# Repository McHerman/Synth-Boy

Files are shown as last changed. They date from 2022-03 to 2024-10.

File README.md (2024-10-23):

# Synth-Boy
## Probably the worlds smallest analog USB powered parafonic synthesizer. 

SB_V1 19 v1

## Techical details 

The Synthboy is an analog 3 oscilator FM-enabled parafonic synthesizer, with a 4 pole voltage controlled filter, an analog ADSR envelope generator and onboard beyboard and TRS Midi control. 
The whole thing is powered from a single protected USB-C input. 

SB V1 21024_1

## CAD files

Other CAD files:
Cad models/Cad models.f3d

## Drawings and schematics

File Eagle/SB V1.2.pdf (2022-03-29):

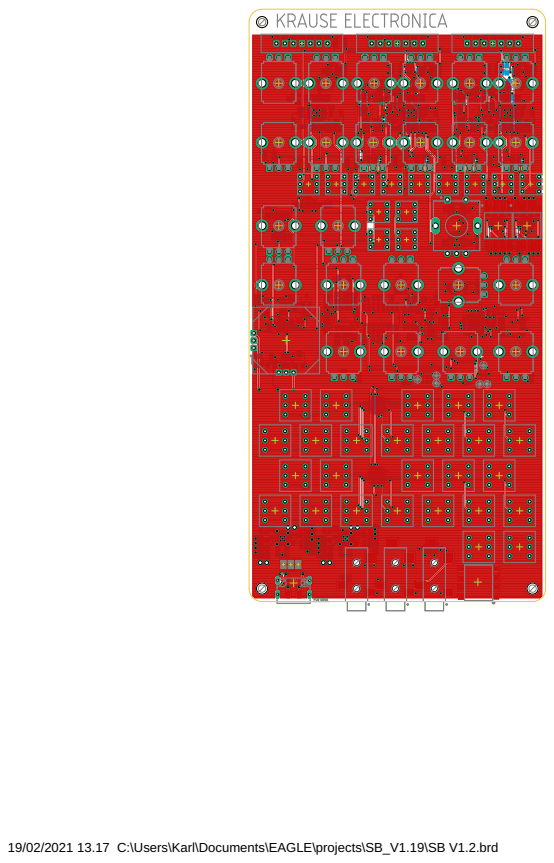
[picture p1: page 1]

19/02/2021 13.17 C:\Users\Karl\Documents\EAGLE\projects\SB_V1.19\SB V1.2.brd

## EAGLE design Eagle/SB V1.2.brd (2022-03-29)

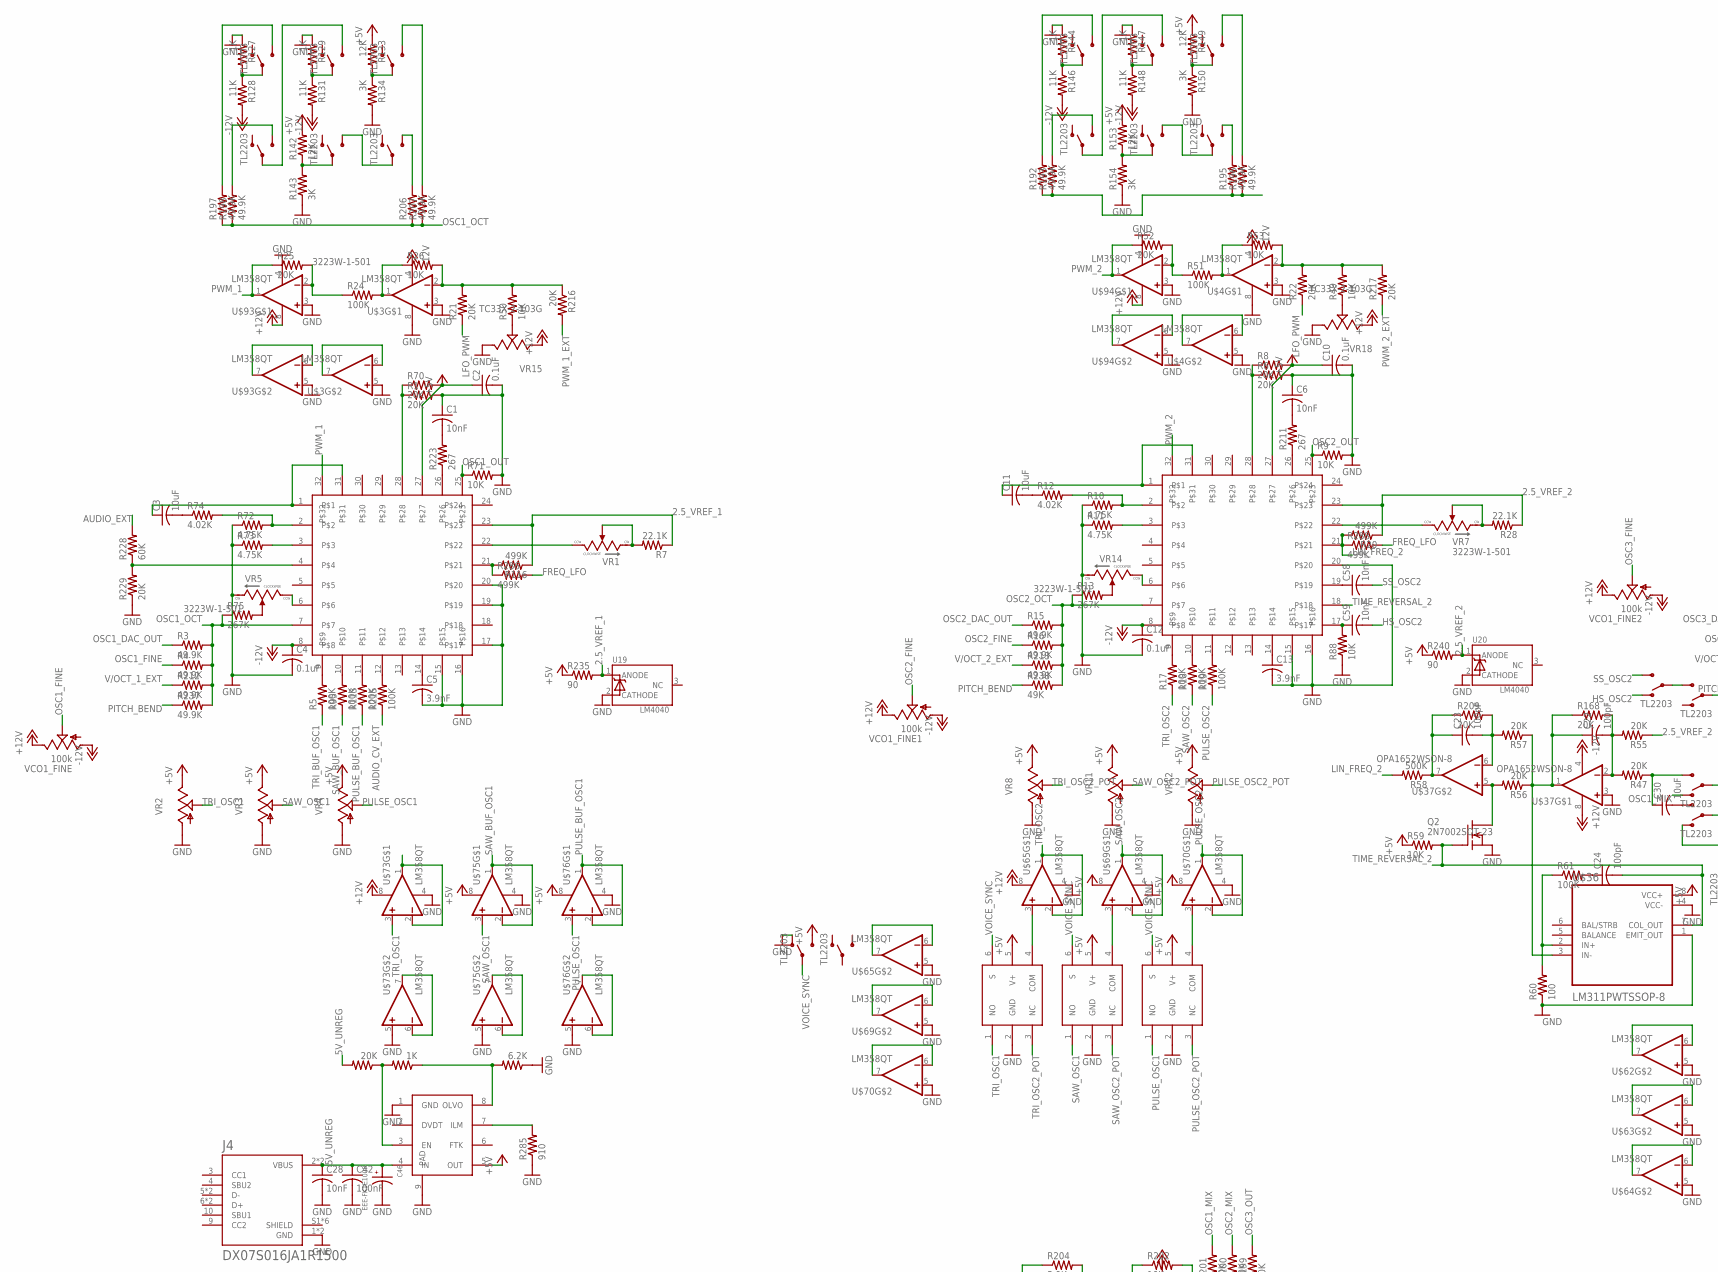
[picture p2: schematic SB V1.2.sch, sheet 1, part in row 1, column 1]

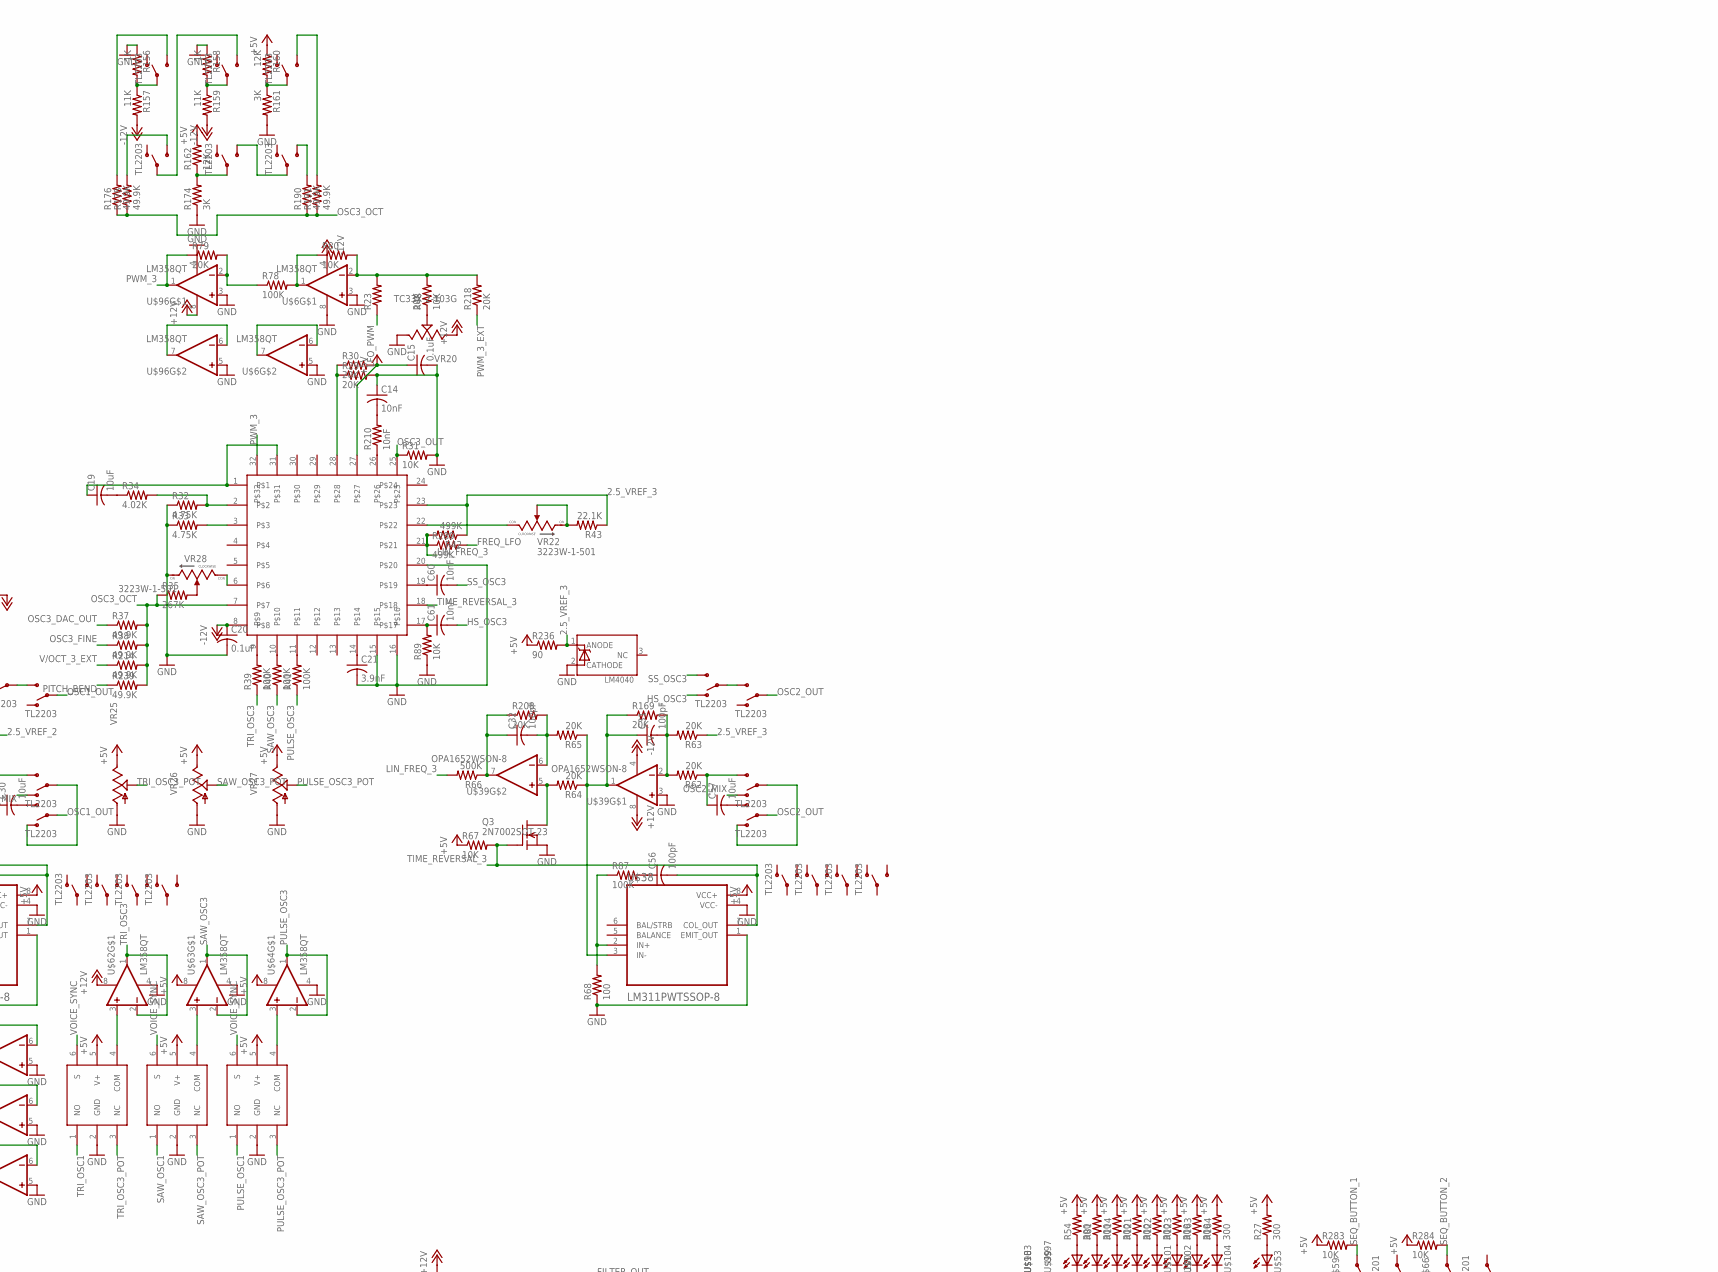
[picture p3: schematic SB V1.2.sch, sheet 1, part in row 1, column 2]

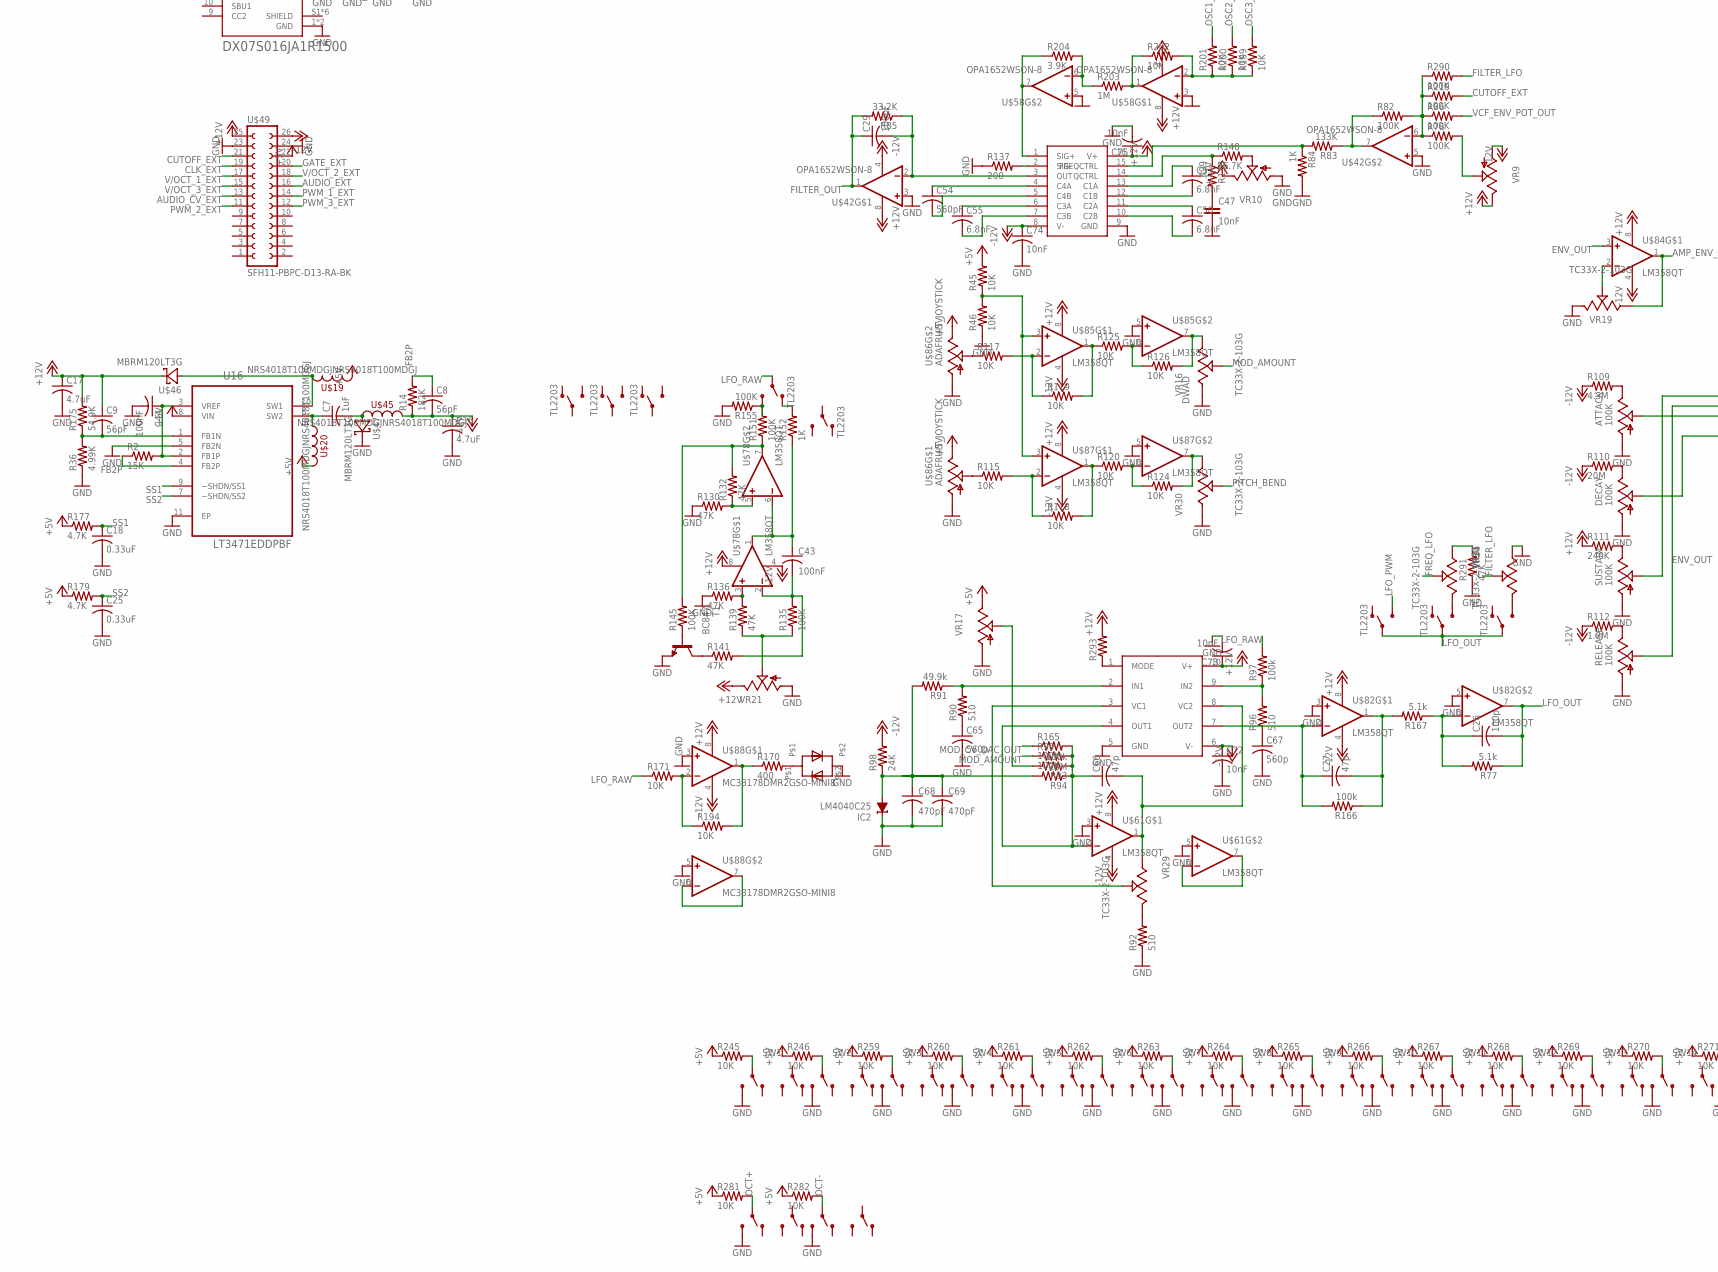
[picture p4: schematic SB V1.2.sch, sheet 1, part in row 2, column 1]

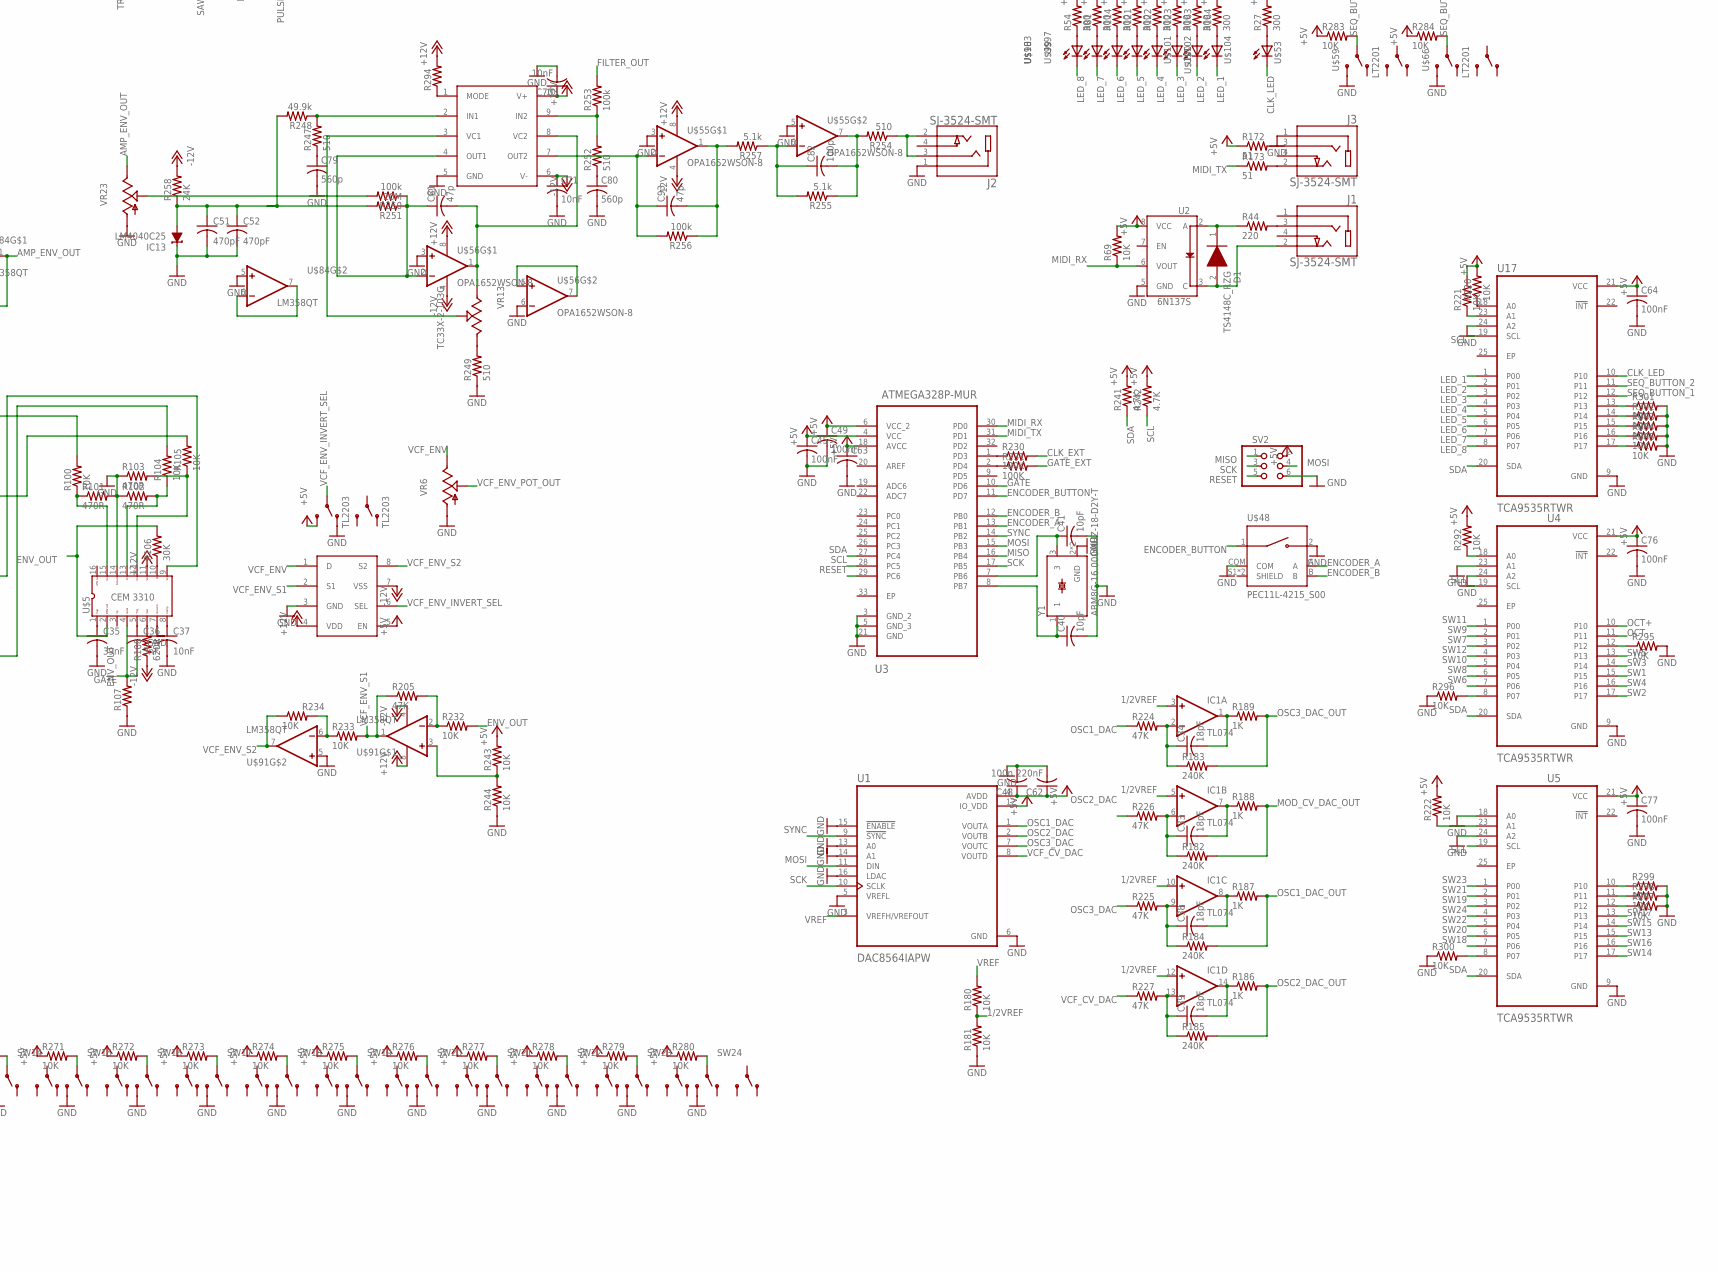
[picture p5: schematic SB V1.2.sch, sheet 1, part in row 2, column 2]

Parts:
1.2K: 1K; R0402
1_DOWN, 1_UP, 2_DOWN, 2_UP, 3_DOWN, 3_UP: TL2203
4.3K: 20K; R0402
ATTACK: 100K; 9MM_SNAP-IN_POT
C1, C6, C14, C37, C47, C58, C59, C60, C61, C70, C71, C72, C73, C74, C75: 10nF; C0402
C2, C4, C10, C12, C15, C20: 0.1uF; C0402
C3, C11, C19, C30, C57: 10uF; C0603
C5, C13, C21: 3.9nF; C0603
C7: 1uF; C0805
C8, C9: 56pF; C0402
C16, C17: 4.7uF; C1206
C18, C25: 0.33uF; C0402
C22, C23, C24, C29, C31, C32, C56: 100pF; C0402
C26, C82: 100p; C0402
C27, C66, C81, C93: 47p; C0402
C28: 10nF; C0603
C33, C34, C38, C39: 18pF; C0402
C35: 39nF; C0402
C36: 3nF; C0402
C40, C41: 10pF; C0402
C42: 100nF; C0603
C43, C44, C45, C49, C64, C76, C77: 100nF; C0402
C46: EEE-FK1E100R; CAPAE430X610N
C48: 100n; C0402
C50, C53, C55: 6.8nF; C0805
C51, C52, C68, C69: 470pF; C0402
C54: 560pF; C0805
C62: 220nF; C0402
C63: C-USC0402; C0402
C65, C67, C79, C80: 560p; C0402
D1: TS4148C_RZG; DIOC1608X75N
DECAY: 100K; 9MM_SNAP-IN_POT
IC1: TL074; TSSOP14
IC2, IC13: LM4040C25; DBZ_R-PDSO-G3
J1, J2, J3: SJ-3524-SMT; CUI_SJ-3524-SMT
J4: DX07S016JA1R1500; JAE_DX07S016JA1R1500
Q2, Q3: 2N7002SOT-23; SOT23-BEC
R1, R6, R8, R21, R22, R23, R25, R29, R30, R47, R52, R55, R56, R57, R62, R63, R64, R65, R70, R79, R168, R169, R208, R209, R216, R217, R218, R229: 20K; R0402
R2: 15K; R0402
R3, R4, R15, R16, R37, R38, R176, R178, R190, R191, R192, R193, R195, R196, R197, R198, R206, R207, R212, R213, R214, R237, R239: 49.9K; R0402
R5, R17, R18, R19, R24, R39, R40, R41, R51, R61, R76, R78, R82, R86, R87, R95, R99, R113, R135, R145, R151, R155, R165, R215, R219, R230, R231, R290: 100K; R0402
R7, R28, R43: 22.1K; R0402
R9, R26, R31, R45, R46, R48, R49, R50, R53, R59, R67, R69, R71, R80, R88, R89, R100, R104, R105, R107, R115, R117, R118, R119, R120, R124, R125, R126, R171, R180, R181, R194, R199, R200, R201, R202, R220, R221, R222, R232, R233, R234, R243, R244, R245, R246, R259, R260, R261, R262, R263, R264, R265, R266, R267, R268, R269, R270, R271, R272, R273, R274, R275, R276, R277, R278, R279, R280, R281, R282, R283, R284, R292, R295, R296, R297, R298, R299, R300, R301, R302, R303, R304, R305: 10K; R0402
R10, R11, R32, R33, R72, R73: 4.75K; R0402
R12, R34, R74: 4.02K; R0402
R13, R35, R75: 267K; R0402
R14: 182K; R0402
R20, R42, R116, R286, R288, R289: 499K; R0402
R27, R54, R81, R114, R121, R122, R123, R163, R164: 300; R0603
R36: 4.99K; R0402
R44: 220; R0402
R58, R66: 500K; R0402
R60, R68: 100; R0402
R77, R167, R255, R257: 5.1k; R0402
R83: 133K; R0402
R84, R127, R129, R144, R147, R152, R156, R158, R186, R187, R188, R189: 1K; R0402
R85: 33.2K; R0402
R90, R92, R96, R247, R249, R252, R254: 510; R0402
R91, R248: 49.9k; R0402
R93, R97, R166, R250, R253, R256: 100k; R0402
R94, R110, R251: 20M; R0402
R98, R258: 24K; R0402
R101, R102, R103: 470R; R0402
R106: 30K; R0402
R108: 620R; R0402
R109: 4.3M; R0402
R111, R182, R183, R184, R185: 240K; R0402
R112: 1.8M; R0402
R128, R131, R146, R148, R157, R159: 11K; R0402
R130, R132, R136, R139, R141, R205, R224, R225, R226, R227, R291: 47K; R0402
R133, R142, R149, R153, R160, R162: 12K; R0402
R134, R143, R150, R154, R161, R174: 3K; R0402
R137: 200; R0402
R138: 499; R0402
R140: 26.7K; R0402
R170: 400; R0603
R172, R173: 51; R0402
R175: 54.9K; R0402
R177, R179, R241, R242: 4.7K; R0402
R203: 1M; R0402
R204: 3.9K; R0402
R210: 10nF; R0402
R211, R223: 267; R0402
R228: 60K; R0402
R235, R236, R240: 90; R0402
R238: 49K; R0402
R285: 910; R0402
R287: 6.2K; R0402
R293, R294: R-US_R0402; R0402
RELEASE: 100K; 9MM_SNAP-IN_POT
SUSTAIN: 100K; 9MM_SNAP-IN_POT
SV2: PINHD-2X3; 2X03
T1: BC847; SOT23
U1: DAC8564IAPW; SOP65P640X120-16N
U2: 6N137S; 8-SMD
U3: ATMEGA328P-MUR; QFN50P500X500X100-33N
U4, U5, U17: TCA9535RTWR; QFN50P400X400X80-25N
U16: LT3471EDDPBF; DFN300X300X80-11N
U19, U20, U21: LM4040; SOT23-3
U$1, U$2, U$7: SSI2130_V2QFN-32; QFN40P400X400X80-33T270N
U$3, U$4, U$6, U$61, U$62, U$63, U$64, U$65, U$69, U$70, U$73, U$75, U$76, U$78, U$82, U$84, U$85, U$87, U$91, U$93, U$94, U$96: LM358QT; SON50P200X200X60-9N
U$5: AS3310DSO-16; SO16
U$8, U$35, U$40, U$41, U$43, U$44, U$51, U$57, U$60, U$71, U$72, U$77, U$79, U$80, U$81, U$92, U$95: TL2203
U$9, U$10, U$11, U$12, U$13, U$14, U$15, U$16, U$17, U$18, U$21, U$22, U$23, U$24, U$25, U$26, U$27, U$28, U$29, U$30, U$31, U$32, U$33, U$34, U$59, U$66, U$67, U$68: LT2201
U$19, U$20, U$45: NRS4018T100MDGJNRS4018T100MDGJ; INDDFN400X400X180-2N
U$36, U$38: LM311PWTSSOP-8; TSSOP8
U$37, U$39, U$42, U$55, U$56, U$58: OPA1652WSON-8; SON50P300X300X80-9T120X200N
U$46, U$47: MBRM120LT3G; DIO_MBRM110LT1G
U$48: PEC11L-4215_S00; XDCR_PEC11R-4215F-S0024
U$49: SFH11-PBPC-D13-RA-BK; FE13-2W
U$53, U$97, U$98, U$99, U$100, U$101, U$102, U$103, U$104: WP914HDT
U$54, U$90: SSI2162SSOP10; SOP100P600X150-10N
U$74: WP483SRSGW
U$83: SSI2144; TSSOP16
U$86: ADAFRUIT_JOYSTICK; ADAFRUIT-JOYSTICK
U$88: MC33178DMR2GSO-MINI8; SOP65P490X110-8N
U$89: TMUX6219DGKRSO-MINI8; SOP65P490X110-8N
U$105, U$106, U$107, U$108, U$109, U$110: NC7SB3157P6XSC-70-6; SOT65P210X110-6N
U$111: TPS259620DDARSOIC-8; SOIC127P600X170-9T240X310N
VCO1_FINE, VCO1_FINE1, VCO1_FINE2: 100k; 9MM_SNAP-IN_POT
VR1, VR5, VR7, VR14, VR22, VR28: 3223W-1-501; TRIM_3223W-1-501
VR2, VR3, VR4, VR6, VR8, VR9, VR10, VR11, VR12, VR17, VR23, VR25, VR26, VR27: 9MM_SNAP-IN_POT_; 9MM_SNAP-IN_POT
VR13, VR15, VR16, VR18, VR19, VR20, VR24, VR29, VR30, VR31: TC33X-2-103G; TRIMMER_TC33X-2-103G
VR21: 9MM_SNAP-IN_POT_NOSNAP_; 9MM_SNAP-IN_POT
Y1: ABM8G-16.000MHZ-18-D2Y-T; OSCSC320X250X100N

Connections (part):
1/2VREF: IC1.3 (+IN), IC1.5 (+IN), IC1.10 (+IN), IC1.12 (+IN), R180.1, R181.2
2.5_VREF_1: R7.1, R116.1, R235.2, U19.1 (ANODE), U$7.23
2.5_VREF_2: R20.1, R28.1, R55.1, R240.2, U20.1 (ANODE), U$1.23
2.5_VREF_3: R42.1, R43.1, R63.1, R236.2, U21.1 (ANODE), U$2.23
5V_UNREG: 4.3K.2, C28.1, C42.1, C46.1, J4.2 (VBUS), J4.11 (VBUS), U$111.4 (IN)
+5V: C2.1, C10.1, C15.1, C45.1, C48.1, C49.1, C62.1, C63.1, C64.1, C76.1, C77.1, R8.2, R27.2, R30.2, R45.2, R54.2, R59.1, R67.1, R69.2, R70.2, R81.2, R114.2, R121.2, R122.2, R123.2, R133.1, R142.2, R149.1, R153.2, R160.1, R162.2, R163.2, R164.2, R172.1, R177.1, R179.1, R220.2, R221.2, R222.2, R235.1, R236.1, R240.1, R241.2, R242.2, R243.2, R245.1, R246.1, R259.1, R260.1, R261.1, R262.1, R263.1, R264.1, R265.1, R266.1, R267.1, R268.1, R269.1, R270.1, R271.1, R272.1, R273.1, R274.1, R275.1, R276.1, R277.1, R278.1, R279.1, R280.1, R281.1, R282.1, R283.1, R284.1, R292.2, SV2.2, U1.4 (AVDD), U1.12 (IO_VDD), U2.8 (VCC), U3.4 (VCC), U3.6 (VCC_2)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
+12V: C9.1, C17.1, C70.1, C73.1, C75.1, IC1.4 (V+), R111.1, R175.2, R293.2, R294.2, U$5.11, U$37.8 (V+), U$39.8 (V+), U$42.8 (V+), U$46.1 (K), U$49.25, U$54.10 (V+), U$55.8 (V+), U$56.8 (V+), U$58.8 (V+), U$61.8 (V+), U$62.8 (V+), U$65.8 (V+), U$73.8 (V+), U$78.8 (V+), U$82.8 (V+), U$83.16 (V+), U$84.8 (V+), U$85.8 (V+), U$87.8 (V+), U$88.8 (V+), U$89.4 (VDD), U$90.10 (V+), U$91.8 (V+), U$93.8 (V+), U$94.8 (V+), U$96.8 (V+), VCO1_FINE.3 (E), VCO1_FINE1.3 (E), VCO1_FINE2.3 (E), VR9.3 (E), VR10.3 (E), VR15.1 (CCW), VR18.1 (CCW), VR20.1 (CCW), VR21.3 (E)
-12V: C4.1, C8.2, C12.1, C16.1, C20.1, C71.1, C72.1, C74.1, IC1.11 (V-), R14.1, R98.2, R108.1, R109.1, R110.1, R112.1, R128.2, R131.2, R146.2, R148.2, R157.2, R159.2, R258.2, U$1.8, U$2.8, U$3.4 (V-), U$4.4 (V-), U$6.4 (V-), U$7.8, U$37.4 (V-), U$39.4 (V-), U$42.4 (V-), U$45.2, U$49.26, U$54.6 (V-), U$55.4 (V-), U$56.4 (V-), U$58.4 (V-), U$61.4 (V-), U$78.4 (V-), U$82.4 (V-), U$83.8 (V-), U$84.4 (V-), U$85.4 (V-), U$87.4 (V-), U$88.4 (V-), U$89.7 (VSS), U$90.6 (V-), U$91.4 (V-), VCO1_FINE.1 (A), VCO1_FINE1.1 (A), VCO1_FINE2.1 (A), VR9.1 (A)
AMP_ENV_OUT: U$84.1 (OUT), VR19.1 (CCW), VR23.3 (E)
AREF_-2.1: C51.1, C52.1, IC13.2 (A), R248.2, R251.2, R258.1
AREF_-2.2: C68.1, C69.1, IC2.2 (A), R91.2, R94.2, R98.1
AUDIO_CV_EXT: R215.1, U$49.13
AUDIO_EXT: R228.2, U$49.16
A_IN_O2B1: R247.2, R248.1, U$54.2 (IN1)
A_IN_O2B2: R90.2, R91.1, U$90.2 (IN1)
CLK_EXT: R230.2, U$49.19
CLK_LED: U17.10, U$53.C
CUTOFF_EXT: R219.2, U$49.21
DWAD: R126.2, U$85.7 (OUT), VR16.3 (CW)
ENCODER_A: U3.13 (PB1), U$48.A
ENCODER_B: U3.12 (PB0), U$48.B
ENCODER_BUTTON: U3.11 (PD7), U$48.1
ENV_OUT: R106.2, R232.2, U$5.2, U$84.3 (+IN)
FB2P: C8.1, R2.1, R14.2, U16.4 (FB2P)
FILTER_LFO: R290.2, VR31.2 (WIPER)
FILTER_OUT: C29.1, R85.2, R253.2, U$42.1 (OUT)
FREQ_LFO: R286.2, R288.2, R289.2, VR24.2 (WIPER)
GATE: C36.2, R107.2, U3.10 (PD6), U$5.4
GATE_EXT: R231.2, U$49.20
GND: ATTACK.1 (A), C1.1, C2.2, C4.2, C5.2, C6.1, C10.2, C12.2, C13.2, C14.1, C15.2, C16.2, C17.2, C18.2, C20.2, C21.2, C25.2, C28.2, C35.2, C37.2, C40.2, C41.2, C42.2, C44.2, C45.2, C46.2, C47.2, C48.2, C49.2, C51.2, C52.2, C62.2, C63.2, C64.2, C65.2, C67.2, C68.2, C69.2, C70.2, C71.2, C72.2, C73.2, C74.2, C75.2, C76.2, C77.2, C79.2, C80.2, DECAY.1 (A), IC2.1 (C), IC13.1 (C), J2.1, J3.1, J4.1 (GND), J4.12 (GND), Q2.C (S), Q3.C (S), R1.2, R6.2, R9.2, R10.1, R11.1, R29.2, R31.2, R32.1, R33.1, R36.1, R46.1, R60.1, R68.1, R71.2, R72.1, R73.1, R84.2, R88.1, R89.1, R92.1, R101.2, R102.1, R103.1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
HS_OSC2: C59.2, U$51.P$3 (O1)
HS_OSC3: C61.2, U$57.P$3 (O1)
LED_1: U17.1 (P00), U$104.C
LED_2: U17.2 (P01), U$103.C
LED_3: U17.3 (P02), U$102.C
LED_4: U17.4 (P03), U$101.C
LED_5: U17.5 (P04), U$100.C
LED_6: U17.6 (P05), U$99.C
LED_7: U17.7 (P06), U$98.C
LED_8: U17.8 (P07), U$97.C
LFO_OUT: C26.2, R77.1, U$79.P$2 (COMMON1), U$80.P$2 (COMMON1), U$81.P$2 (COMMON1), U$82.7 (OUT)
LFO_PWM: R21.1, R22.1, R23.1, U$79.P$1 (S1)
LFO_RAW: R97.2, R171.1, U$77.P$2 (COMMON1)
LIN_FREQ_2: R20.2, R58.2, R288.1, U$1.21
LIN_FREQ_3: R42.2, R66.2, R289.1, U$2.21
MIDI_RX: R69.1, U2.6 (VOUT), U3.30 (PD0)
MIDI_TX: R173.1, U3.31 (PD1)
MISO: SV2.1, U3.16 (PB4)
MIX2_OUT: R204.1, U$58.7 (OUT), U$83.1 (SIG+)
MOD_AMOUNT: R99.1, VR16.2 (WIPER)
MOD_CV_DAC_OUT: R165.1, R182.2, R188.2
MOSI: SV2.4, U1.11 (DIN), U3.15 (PB3)
unnamed: R5.2, U$7.9
unnamed: C30.2, U$8.P$1 (S1)
unnamed: C57.2, U$40.P$1 (S1)
unnamed: R116.2, R286.1, U$7.21
unnamed: U$7.22, VR1.1
unnamed: R7.2, VR1.2, VR1.3
unnamed: U$84.2 (-IN), VR19.2 (WIPER)
unnamed: R6.1, R8.1, U$1.28
unnamed: U$8.P$3 (O1), U$35.P$2 (COMMON1)
unnamed: U$7.6, VR5.1
unnamed: R210.1, U$2.26
unnamed: R27.1, U$53.A
unnamed: R75.2, VR5.2
unnamed: U$40.P$3 (O1), U$41.P$2 (COMMON1)
unnamed: R10.2, R12.2, U$1.2
unnamed: C11.2, R12.1
unnamed: C11.1, U$1.1, U$1.31
unnamed: R132.2, R145.2, R151.1, U$78.7 (OUT)
unnamed: R17.2, U$1.9
unnamed: R18.2, U$1.10
unnamed: R19.2, U$1.11
unnamed: C13.1, U$1.14
unnamed: R54.1, U$97.A
unnamed: U$93.6 (-IN), U$93.7 (OUT)
unnamed: U$1.22, VR7.1
unnamed: R29.1, R30.1, U$2.28
unnamed: R24.2, R26.1, U$3.1 (OUT)
unnamed: R28.2, VR7.2, VR7.3
unnamed: U$65.3 (+IN), U$105.4 (COM)
unnamed: R24.1, R25.2, U$93.2 (-IN)
unnamed: R199.1, R200.1, R201.1, R202.2, U$58.2 (-IN)
unnamed: R170.2, U$74.P$1
unnamed: R11.2, U$1.3
unnamed: U$43.P$1 (S1), U$51.P$2 (COMMON1)
unnamed: C44.1, R2.2, U16.2 (FB1P), U16.3 (VREF)
unnamed: U$1.6, VR14.1
unnamed: R13.2, VR14.2
unnamed: U$44.P$1 (S1), U$57.P$2 (COMMON1)
unnamed: U$69.3 (+IN), U$106.4 (COM)
unnamed: C22.2, R47.2, R55.2, R168.2, U$37.2 (-IN)
unnamed: C14.2, R210.2
unnamed: R32.2, R34.2, U$2.2
unnamed: C19.2, R34.1
unnamed: C19.1, U$2.1, U$2.31
unnamed: C9.2, R36.2, R175.1, U16.1 (FB1N)
unnamed: R39.2, U$2.9
unnamed: R40.2, U$2.10
unnamed: R41.2, U$2.11
unnamed: C21.1, U$2.14
unnamed: U$70.3 (+IN), U$107.4 (COM)
unnamed: U$2.22, VR22.1
unnamed: R43.2, VR22.2, VR22.3
unnamed: R33.2, U$2.3
unnamed: C22.1, R56.1, R57.1, R168.1, U$36.3 (IN-), U$37.1 (OUT)
unnamed: U$2.6, VR28.1
unnamed: R35.2, VR28.2
unnamed: C32.2, R65.2, R208.2, U$39.6 (-IN)
unnamed: C23.1, R58.1, R209.1, U$37.7 (OUT)
unnamed: Q3.E (D), R64.2, U$39.5 (+IN)
unnamed: R51.2, R53.1, U$4.1 (OUT)
unnamed: R51.1, R52.2, U$94.2 (-IN)
unnamed: C43.1, R152.1, U$78.1 (OUT), U$78.6 (-IN)
unnamed: R171.2, R194.1, U$88.2 (-IN)
unnamed: R60.2, R61.1, U$36.2 (IN+)
unnamed: C24.1, R61.2
unnamed: U$62.3 (+IN), U$108.4 (COM)
unnamed: C30.1, R47.1, U$35.P$1 (S1)
unnamed: R115.1, U$86.P$2 (S)
unnamed: C31.2, R62.2, R63.2, R169.2, U$39.2 (-IN)
unnamed: C31.1, R64.1, R65.1, R169.1, U$38.3 (IN-), U$39.1 (OUT)
unnamed: Q2.E (D), R56.2, U$37.5 (+IN)
unnamed: C32.1, R66.1, R208.1, U$39.7 (OUT)
unnamed: C23.2, R57.2, R209.2, U$37.6 (-IN)
unnamed: R68.2, R87.1, U$38.2 (IN+)
unnamed: C56.1, R87.2
unnamed: C57.1, R62.1, U$41.P$1 (S1)
unnamed: R1.1, R70.1, U$7.28
unnamed: R211.1, U$1.26
unnamed: R72.2, R74.2, U$7.2
unnamed: C3.2, R74.1
unnamed: C3.1, U$7.1, U$7.31
unnamed: C7.1, U16.6 (SW2), U$20.1
unnamed: R78.2, R80.1, U$6.1 (OUT)
unnamed: R78.1, R79.2, U$96.2 (-IN)
unnamed: R136.2, R139.2, U$78.3 (+IN)
unnamed: D1.1 (K), R44.1, U2.2 (A)
unnamed: D1.2 (A), J1.2, U2.3 (C)
unnamed: R170.1, R194.2, U$88.1 (OUT)
unnamed: J1.3, R44.2
unnamed: U$88.6 (-IN), U$88.7 (OUT)
unnamed: C6.2, R211.2
unnamed: R95.2, U$7.10
unnamed: R113.2, U$7.11
unnamed: C58.1, U$1.19
unnamed: R233.1, R234.2, U$91.6 (-IN)
unnamed: C59.1, R88.2, U$1.17
unnamed: R76.1, R82.2, R86.1, R219.1, R290.1, U$42.6 (-IN)
unnamed: R221.1, U17.23 (A1)
unnamed: C66.1, R93.1, R94.1, R99.2, R165.2, U$61.2 (-IN), U$90.4 (OUT1)
unnamed: C61.1, R89.2, U$2.17
unnamed: C93.1, R256.2, U$54.7 (OUT2), U$55.2 (-IN)
unnamed: R76.2, VR9.2 (S)
unnamed: C60.1, U$2.19
unnamed: U$63.3 (+IN), U$109.4 (COM)
unnamed: U$64.3 (+IN), U$110.4 (COM)
unnamed: U$62.6 (-IN), U$62.7 (OUT)
unnamed: U$63.6 (-IN), U$63.7 (OUT)
unnamed: U$64.6 (-IN), U$64.7 (OUT)
unnamed: U$65.6 (-IN), U$65.7 (OUT)
unnamed: U$69.6 (-IN), U$69.7 (OUT)
unnamed: U$70.6 (-IN), U$70.7 (OUT)
unnamed: R117.1, U$86.P$5 (S)
unnamed: C5.1, U$7.14
unnamed: R81.1, U$98.A
unnamed: R117.2, R119.1, U$85.2 (-IN)
unnamed: U$73.6 (-IN), U$73.7 (OUT)
unnamed: U$75.6 (-IN), U$75.7 (OUT)
unnamed: U$76.6 (-IN), U$76.7 (OUT)
unnamed: C65.1, R90.1
unnamed: R92.2, VR29.3 (CW)
unnamed: U$90.3 (VC1), VR29.2 (WIPER)
unnamed: C66.2, U$61.1 (OUT), U$90.8 (VC2), VR29.1 (CCW)
unnamed: C67.1, R96.1
unnamed: C27.1, R166.2, U$82.2 (-IN), U$90.7 (OUT2)
unnamed: C55.1, U$83.6 (C3A)
unnamed: R96.2, R97.1, U$90.9 (IN2)
unnamed: R119.2, R125.1, U$85.1 (OUT)
unnamed: R100.1, R101.1, U$5.15
unnamed: R106.1, U$5.10
unnamed: R102.2, R104.1, U$5.13
unnamed: R103.2, R105.1, U$5.12
unnamed: R82.1, R83.1, U$42.7 (OUT)
unnamed: J3.3, R172.2
unnamed: C35.1, U$5.1
unnamed: C36.1, U$5.5
unnamed: C37.1, U$5.8
unnamed: C7.2, U$45.1, U$47.2 (A)
unnamed: J3.2, R173.2
unnamed: R108.2, U$5.6
unnamed: ATTACK.3 (E), R109.2
unnamed: DECAY.3 (E), R110.2
unnamed: R111.2, SUSTAIN.3 (E)
unnamed: R112.2, RELEASE.3 (E)
unnamed: ATTACK.2 (S), R100.2
unnamed: DECAY.2 (S), R105.2
unnamed: SUSTAIN.2 (S), U$5.9
unnamed: R104.2, RELEASE.2 (S)
unnamed: R205.2, R232.1, U$91.2 (-IN)
unnamed: R115.2, R118.1, U$87.2 (-IN)
unnamed: U$84.6 (-IN), U$84.7 (OUT)
unnamed: R223.1, U$7.26
unnamed: U$80.P$1 (S1), VR24.3 (CW)
unnamed: C1.2, R223.2
unnamed: C34.1, IC1.2 (-IN), R183.1, R224.2
unnamed: R73.2, U$7.3
unnamed: R93.2, VR17.2 (S)
unnamed: R118.2, R120.1, U$87.1 (OUT)
unnamed: R120.2, R124.1, U$87.6 (-IN)
unnamed: R114.1, U$99.A
unnamed: R124.2, U$87.7 (OUT), VR30.3 (CW)
unnamed: R125.2, R126.1, U$85.6 (-IN)
unnamed: C39.1, IC1.13 (-IN), R185.1, R227.2
unnamed: C43.2, R135.2, R141.2, U$78.2 (-IN)
unnamed: R250.2, VR23.2 (S)
unnamed: 1_DOWN.P$2 (COMMON1), R127.2, R128.1
unnamed: C38.1, IC1.9 (-IN), R184.1, R225.2
unnamed: C41.1, U3.7 (PB6), Y1.3
unnamed: C33.1, IC1.6 (-IN), R182.1, R226.2
unnamed: C40.1, U3.8 (PB7), Y1.1
unnamed: R129.2, R131.1, U$92.P$2 (COMMON1)
unnamed: U16.10 (SW1), U$19.2, U$46.2 (A)
unnamed: C79.1, R247.1
unnamed: 1_UP.P$5 (COMMON1), R133.2, R134.1
unnamed: R142.1, R143.2, U$92.P$5 (COMMON1)
unnamed: R135.1, R139.1, VR21.2 (S)
unnamed: 1_UP.P$2 (COMMON1), U$92.P$4 (S1)
unnamed: 1_DOWN.P$5 (COMMON1), U$92.P$1 (S1)
unnamed: R202.1, R203.2, U$58.1 (OUT)
unnamed: R141.1, T1.3 (C)
unnamed: C55.2, U$83.7 (C3B)
unnamed: R145.1, T1.1 (B)
unnamed: C53.1, U$83.13 (C1A)
unnamed: 1_DOWN.P$1 (S1), R197.2
unnamed: 1_DOWN.P$4 (S1), R198.2
unnamed: R121.1, U$100.A
unnamed: R122.1, U$101.A
unnamed: R130.2, R132.1, U$78.5 (+IN)
unnamed: C53.2, U$83.12 (C1B)
unnamed: R151.2, R155.1, U$77.P$1 (S1)
unnamed: C50.1, U$83.11 (C2A)
unnamed: R152.2, U$77.P$3 (O1)
unnamed: C50.2, U$83.10 (C2B)
unnamed: 1_UP.P$1 (S1), R206.2
unnamed: 1_UP.P$4 (S1), R207.2
unnamed: 2_DOWN.P$2 (COMMON1), R144.2, R146.1
unnamed: R147.2, R148.1, U$60.P$2 (COMMON1)
unnamed: R123.1, U$102.A
unnamed: 2_UP.P$5 (COMMON1), R149.2, R150.1
unnamed: R163.1, U$103.A
unnamed: R153.1, R154.2, U$60.P$5 (COMMON1)
unnamed: R164.1, U$104.A
unnamed: 2_UP.P$2 (COMMON1), U$60.P$4 (S1)
unnamed: R45.1, R46.2, U$85.3 (+IN), U$87.3 (+IN)
unnamed: C34.2, IC1.1 (OUT), R189.1
unnamed: C33.2, IC1.7 (OUT), R188.1
unnamed: C38.2, IC1.8 (OUT), R187.1
unnamed: C39.2, IC1.14 (OUT), R186.1
unnamed: R297.1, U5.12
unnamed: R298.1, U5.11
unnamed: R299.1, U5.10
unnamed: R300.2, U5.8 (P07)
unnamed: R243.1, R244.2, U$91.3 (+IN)
unnamed: R295.1, U4.12
unnamed: R228.1, R229.2, U$7.4
unnamed: U$81.P$1 (S1), VR31.3 (CW)
unnamed: R296.2, U4.8 (P07)
unnamed: R230.1, U3.1 (PD3)
unnamed: R231.1, U3.2 (PD4)
unnamed: U$3.6 (-IN), U$3.7 (OUT)
unnamed: U$94.6 (-IN), U$94.7 (OUT)
unnamed: C26.1, R77.2, R167.1, U$82.6 (-IN)
unnamed: C27.2, R166.1, R167.2, U$82.1 (OUT)
unnamed: U$61.6 (-IN), U$61.7 (OUT)
unnamed: U$4.6 (-IN), U$4.7 (OUT)
unnamed: U$6.6 (-IN), U$6.7 (OUT)
unnamed: U$96.6 (-IN), U$96.7 (OUT)
unnamed: R291.2, VR24.1 (CCW)
unnamed: R220.1, U17.18 (A0)
unnamed: R222.1, U5.23 (A1)
unnamed: R292.1, U4.18 (A0)
unnamed: R83.2, R84.1, U$83.15 (FREQCTRL)
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

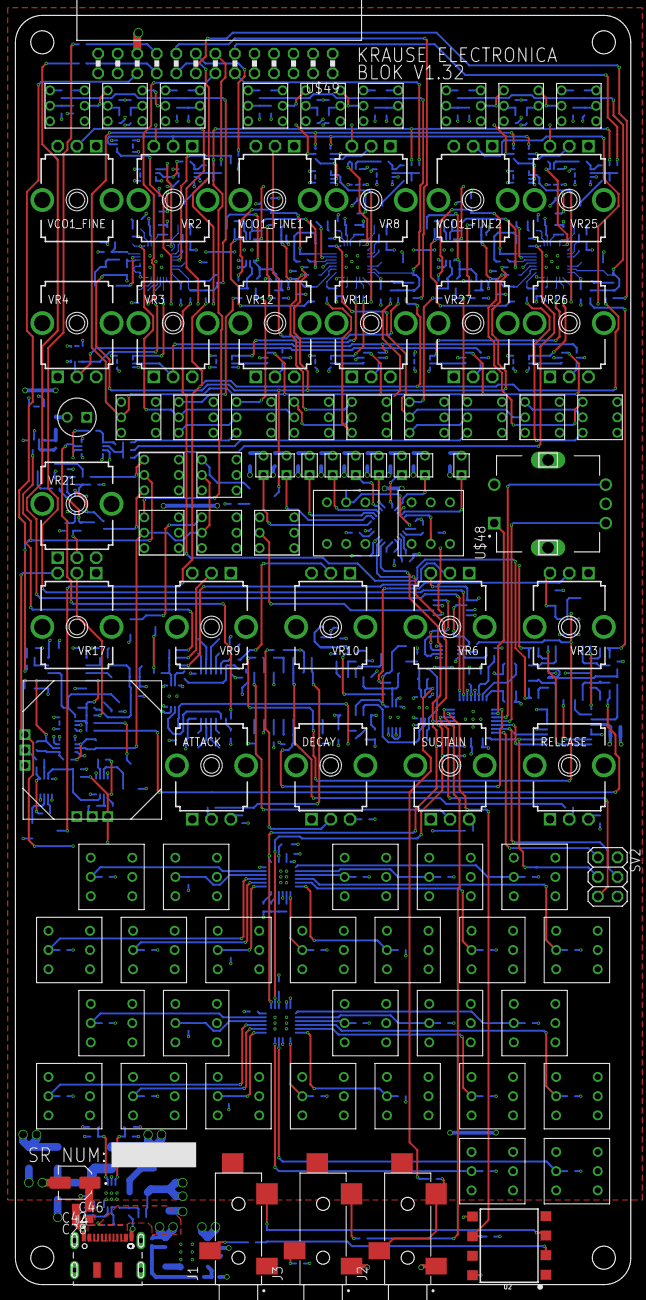
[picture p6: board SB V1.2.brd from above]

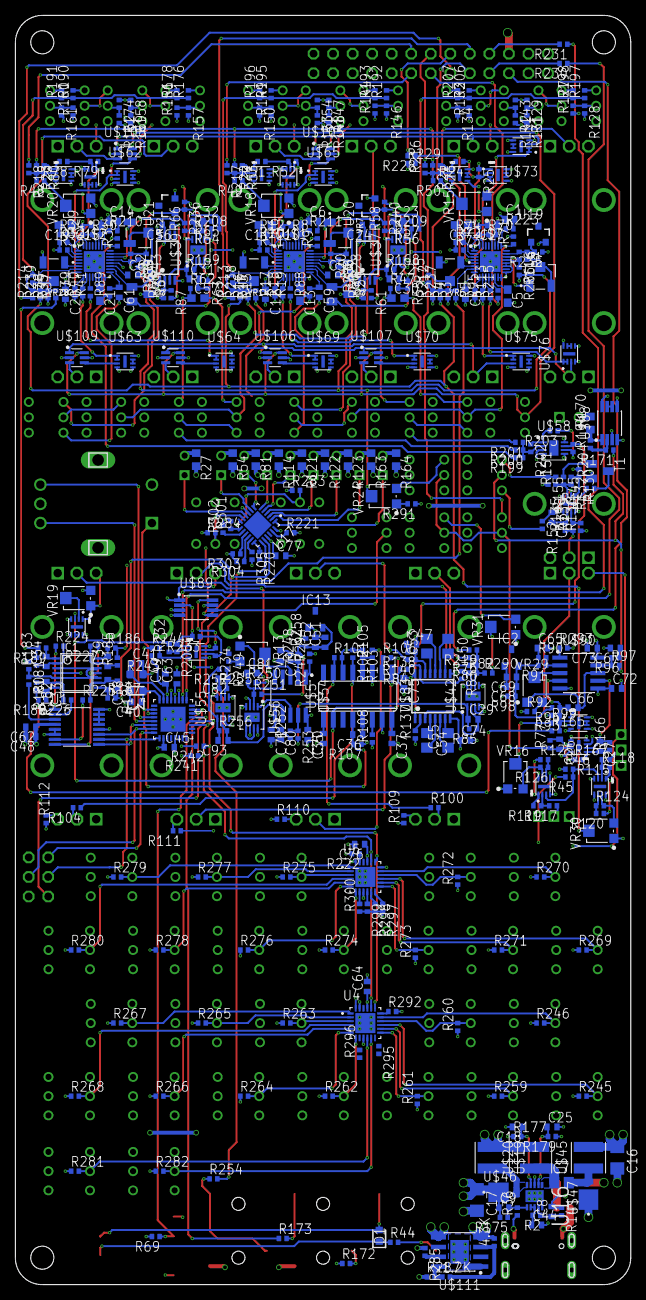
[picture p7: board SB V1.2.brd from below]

Board: 4 copper layers, 80.0 x 165.0 mm, 565 parts (470 on the bottom side), 426 nets.

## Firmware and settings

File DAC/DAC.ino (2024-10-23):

#if defined(ARDUINO) && ARDUINO >= 100
#include "Arduino.h"
#else
#include "WProgram.h"
#endif

#include "clsPCA9555.h"
#include "Wire.h"

#include <SPI.h>
#include <DAC7565.h>

#define S1 13 
#define S2 15 
#define S3 12 
#define S4 14 
#define S5 11 
#define S6 6 
#define S7 2 
#define S8 5 
#define S9 1 
#define S10 4 
#define S11 0 
#define S12 3 

#define S13 29 //13+16
#define S14 31 //15+16
#define S15 28 //12+16
#define S16 30 //14+16
#define S17 27 //11+16
#define S18 22 //6+16
#define S19 18 //2+16
#define S20 21 //5+16
#define S21 17 //1+16
#define S22 20 //4+16
#define S23 16 //0+16
#define S24 19 //3+16

DAC dac(-1, 10, -1, 11, 13);

PCA9555 ioport(0x23);
PCA9555 ioport2(0x22);
PCA9555 ioport3(0x21);

void setup() 
{
  // Initialize the DAC
  dac.init();
  
  // Set DAC reference to be powered up, VREF = 2.5V
  // this mean that vout will be able to go from 0V to 2.5V (full scale)
  dac.setReference(DAC_REFERENCE_ALWAYS_POWERED_UP);

  // Set all outputs to 1V
  dac.writeChannel(DAC_CHANNEL_ALL, 39158);

  ioport.begin();

  ioport.setClock(400000);

  ioport2.begin();

  ioport2.setClock(400000);

  ioport3.begin();

  ioport3.setClock(400000);


  for (uint8_t i = 0; i < 15; i++){
    ioport.pinMode(i, OUTPUT);
  }

  for (uint8_t i = 0; i < 15; i++){
    ioport2.pinMode(i, INPUT);
  }

  for (uint8_t i = 0; i < 15; i++){
    ioport3.pinMode(i, INPUT);
  }
  
  pinMode(6, OUTPUT); 
  
}


void loop() {

  unsigned long IO = ((((unsigned long)ioport2.digitalReadWord() | 1920)<<16) | (ioport3.digitalReadWord() | 1152)); //Bitmask for unused inputs on IO extenders

  switch(IO){

    case(~(1UL<<S1)):
    
      oscWrite(0); 
      digitalWrite(6,HIGH);
      ioport.digitalWrite(8, LOW);
      break;

    case(~(1UL<<S2)):
    
      oscWrite(1); 
      digitalWrite(6,HIGH);
      ioport.digitalWrite(8, LOW);
      break;
          
    case(~(1UL<<S3)):

      oscWrite(2); 
      digitalWrite(6,HIGH);
      ioport.digitalWrite(8, LOW);
      break;
      
    case(~(1UL<<S4)):

      oscWrite(3); 
      digitalWrite(6,HIGH);
      ioport.digitalWrite(8, LOW);
      break;
      
    case(~(1UL<<S5)):

      oscWrite(4); 
      digitalWrite(6,HIGH);
      ioport.digitalWrite(8, LOW);
      break;
      
    case(~(1UL<<S6)):

      oscWrite(5); 
      digitalWrite(6,HIGH);
      ioport.digitalWrite(8, LOW);
      break;
      
    case(~(1UL<<S7)):

      oscWrite(6);
      digitalWrite(6,HIGH);
      ioport.digitalWrite(8, LOW); 
      break;
      
    case(~(1UL<<S8)):

      oscWrite(7); 
      digitalWrite(6,HIGH);
      ioport.digitalWrite(8, LOW);
      break;
      
    case(~(1UL<<S9)):

      oscWrite(8); 
      digitalWrite(6,HIGH);
      ioport.digitalWrite(8, LOW);
      break;
           
    case(~(1UL<<S10)):
    
      oscWrite(9);  
      digitalWrite(6,HIGH);
      ioport.digitalWrite(8, LOW);
      break;
      
    case(~(1UL<<S11)):
    
      oscWrite(10); 
      digitalWrite(6,HIGH);
      ioport.digitalWrite(8, LOW);
      break;
      
    case(~(1UL<<S12)):
    
      oscWrite(11); 
      digitalWrite(6,HIGH);
      ioport.digitalWrite(8, LOW);
      break;
      
    case(~(1UL<<S13)):
    
      oscWrite(12); 
      digitalWrite(6,HIGH);
      ioport.digitalWrite(8, LOW);
      break;
      
    case(~(1UL<<S14)):
    
      oscWrite(13); 
      digitalWrite(6,HIGH);
      ioport.digitalWrite(8, LOW);
      break;
      
    case(~(1UL<<S15)):
    
      oscWrite(14); 
      digitalWrite(6,HIGH);
      ioport.digitalWrite(8, LOW);
      break;
      
    case(~(1UL<<S16)):

      oscWrite(15); 
      digitalWrite(6,HIGH);
      ioport.digitalWrite(8, LOW);
      break;

    case(~(1UL<<S17)):

      oscWrite(16); 
      digitalWrite(6,HIGH);
      ioport.digitalWrite(8, LOW);
      break;

    case(~(1UL<<S18)):

      oscWrite(17); 
      digitalWrite(6,HIGH);
      ioport.digitalWrite(8, LOW);
      break;

    case(~(1UL<<S19)):

      oscWrite(18); 
      digitalWrite(6,HIGH);
      ioport.digitalWrite(8, LOW);
      break;

    case(~(1UL<<S20)):

      oscWrite(19); 
      digitalWrite(6,HIGH);
      ioport.digitalWrite(8, LOW);
      break;

    case(~(1UL<<S21)):

      oscWrite(20); 
      digitalWrite(6,HIGH);
      ioport.digitalWrite(8, LOW);
      break;

    case(~(1UL<<S22)):

      oscWrite(21); 
      digitalWrite(6,HIGH);
      ioport.digitalWrite(8, LOW);
      break;

    case(~(1UL<<S23)):

      oscWrite(22); 
      digitalWrite(6,HIGH);
      ioport.digitalWrite(8, LOW);
      break;

    case(~(1UL<<S24)):

      oscWrite(23); 
      digitalWrite(6,HIGH);
      ioport.digitalWrite(8, LOW);
      break;

    default:

      digitalWrite(6,LOW);
      ioport.digitalWrite(8, HIGH);
      break;
    
  }
}

void oscWrite(int note){
 
  dac.writeChannel(DAC_CHANNEL_B, 39158 - (note * 30));
  dac.writeChannel(DAC_CHANNEL_A, 39158 - (note * 30));
  dac.writeChannel(DAC_CHANNEL_C, 39158 - (note * 30));
      
}

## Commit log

2022-03-29 Updated Arduino
2022-03-29 Create Cad models.f3d
    [Cad models.f3d]
